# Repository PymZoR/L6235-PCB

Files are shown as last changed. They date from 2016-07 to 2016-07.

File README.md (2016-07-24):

# L6235-PCB

Implements the "typical application" ([datasheet](./doc/datasheet.pdf)) as a single sided PCB.  

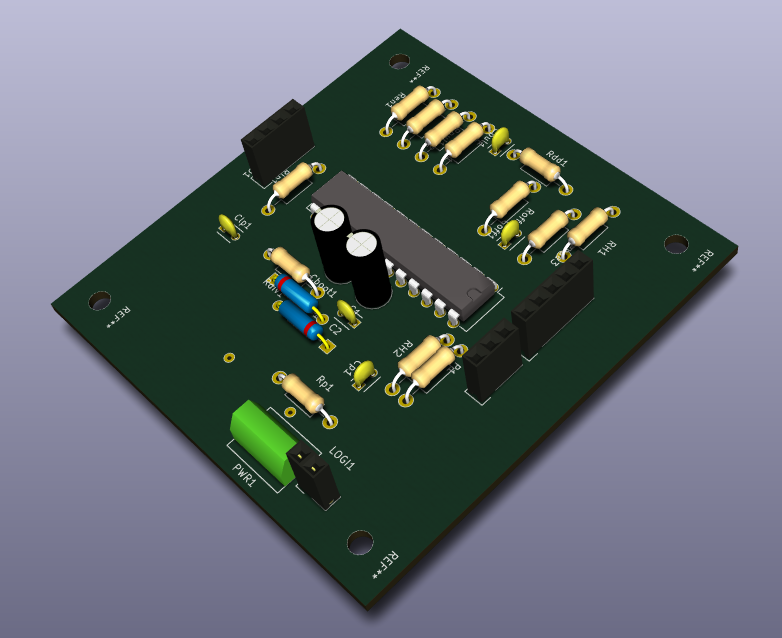
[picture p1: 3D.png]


## Specifications

- Require a 5V logic supply voltage (LOGI1), as well as a power one (PWR1)
- 69.8*66mm. 4 M3 mounting holes
- Variable reference voltage as described in the ([application note](./doc/application_note.pdf)) through VREF pin (CMD1)

## Schematic

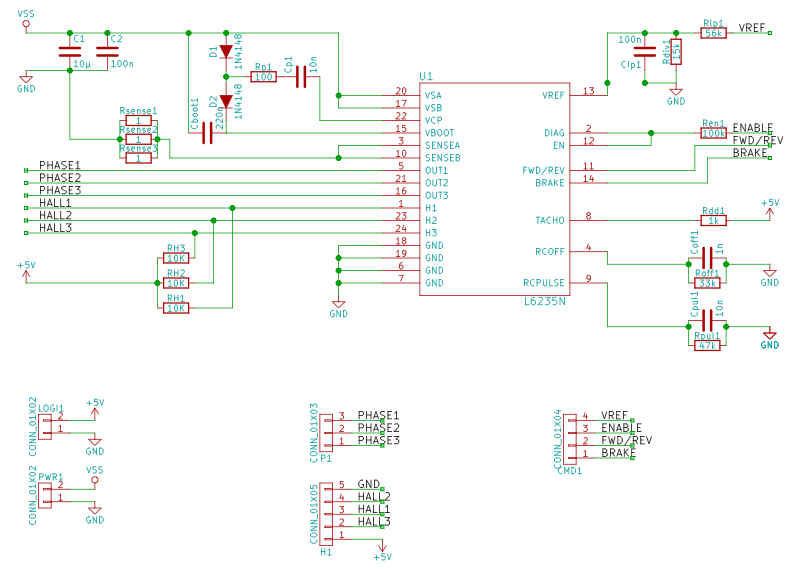
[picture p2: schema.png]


## PCB

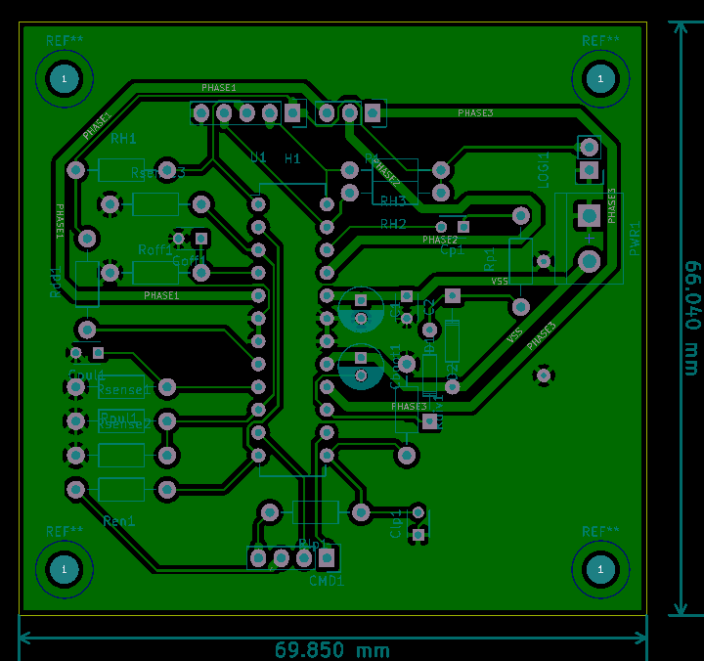
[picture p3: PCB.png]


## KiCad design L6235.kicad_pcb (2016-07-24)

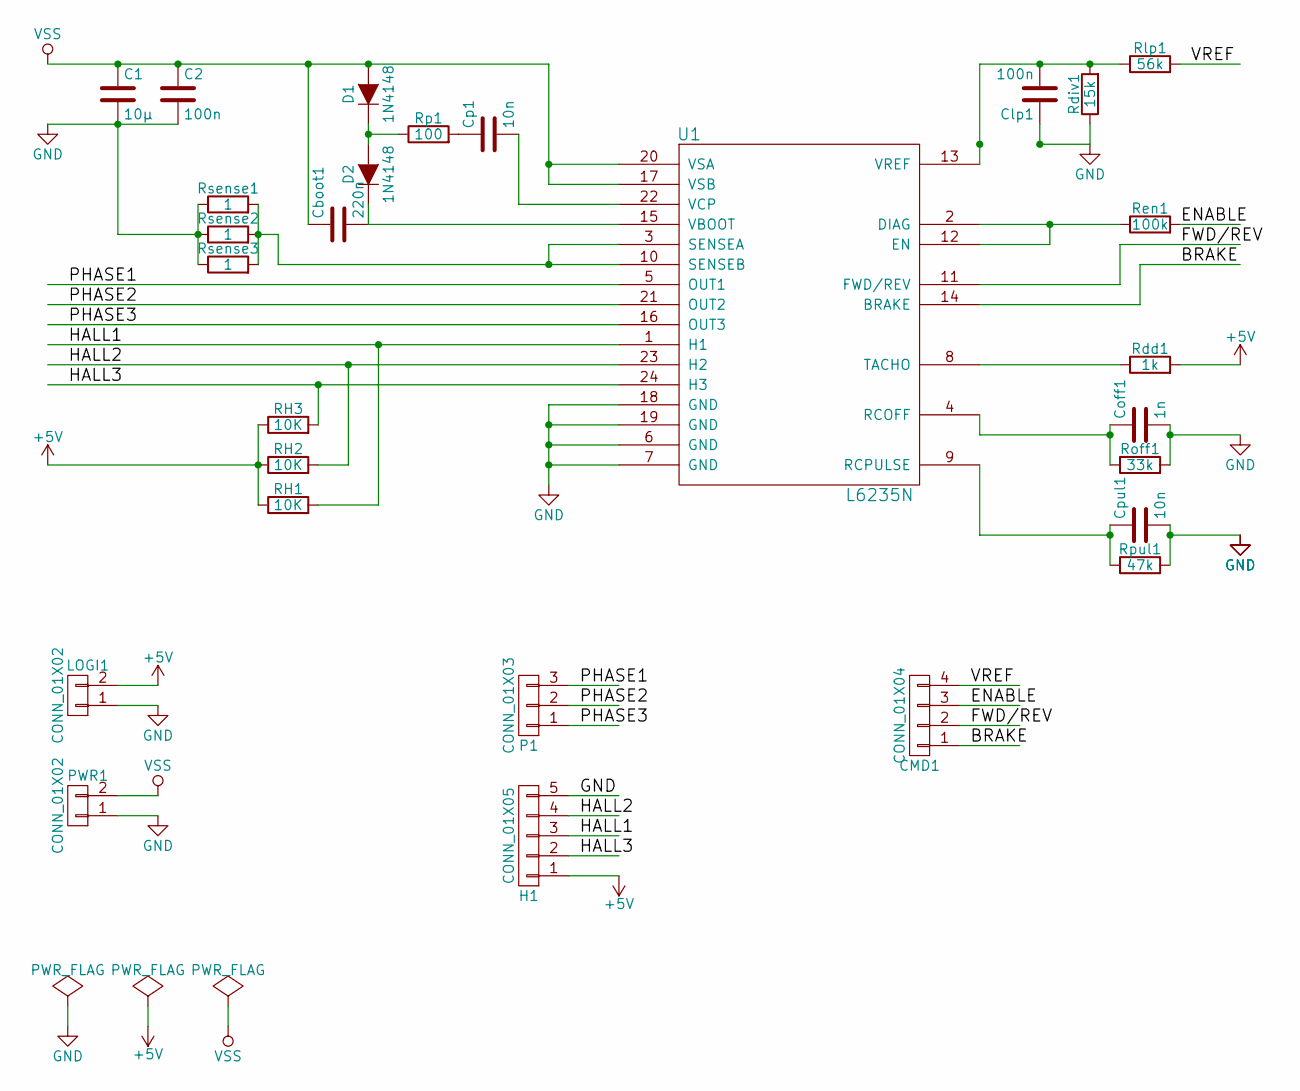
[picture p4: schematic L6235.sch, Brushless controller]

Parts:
C1: 10µ; C_Radial_D5_L11_P2
C2: 100n; C_Disc_D3_P2.5
CMD1: CONN_01X04; Socket_Strip_Straight_1x04
Cboot1: 220n; C_Radial_D5_L11_P2
Clp1: 100n; C_Disc_D3_P2.5
Coff1: 1n; C_Disc_D3_P2.5
Cp1: 10n; C_Disc_D3_P2.5
Cpul1: 10n; C_Disc_D3_P2.5
D1, D2: 1N4148; Diode_DO-35_SOD27_Horizontal_RM10
H1: CONN_01X05; Socket_Strip_Straight_1x05
LOGI1: CONN_01X02; Socket_Strip_Straight_1x02
P1: CONN_01X03; Socket_Strip_Straight_1x03
PWR1: CONN_01X02; bornier2
RH1, RH2, RH3: 10K; Resistor_Horizontal_RM10mm
Rdd1: 1k; Resistor_Horizontal_RM10mm
Rdiv1: 15k; Resistor_Horizontal_RM10mm
Ren1: 100k; Resistor_Horizontal_RM10mm
Rlp1: 56k; Resistor_Horizontal_RM10mm
Roff1: 33k; Resistor_Horizontal_RM10mm
Rp1: 100; Resistor_Horizontal_RM10mm
Rpul1: 47k; Resistor_Horizontal_RM10mm
Rsense1, Rsense2, Rsense3: 1; Resistor_Horizontal_RM10mm
U1: L6235N; DIP-24_W7.62mm

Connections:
+5V: H1.1, LOGI1.2, RH1.1, RH2.1, RH3.1, Rdd1.2
/BRAKE: CMD1.1, U1.14 (BRAKE)
/ENABLE: CMD1.3, Ren1.2
/FWD/REV: CMD1.2, U1.11 (FWD/REV)
/HALL1: H1.3, RH1.2, U1.1 (H1)
/HALL2: H1.4, RH2.2, U1.23 (H2)
/HALL3: H1.2, RH3.2, U1.24 (H3)
/PHASE1: P1.3, U1.5 (OUT1)
/PHASE2: P1.2, U1.21 (OUT2)
/PHASE3: P1.1, U1.16 (OUT3)
/VREF: CMD1.4, Rlp1.2
GND: C1.2, C2.2, Clp1.1, Coff1.2, Cpul1.2, H1.5, LOGI1.1, PWR1.1, Rdiv1.1, Roff1.2, Rpul1.2, Rsense1.1, Rsense2.1, Rsense3.1, U1.6 (GND), U1.7 (GND), U1.18 (GND), U1.19 (GND)
unnamed: Cboot1.2, D2.1 (K), U1.15 (VBOOT)
unnamed: Clp1.2, Rdiv1.2, Rlp1.1, U1.13 (VREF)
unnamed: Coff1.1, Roff1.1, U1.4 (RCOFF)
unnamed: Cp1.1, Rp1.2
unnamed: Cp1.2, U1.22 (VCP)
unnamed: Cpul1.1, Rpul1.1, U1.9 (RCPULSE)
unnamed: D1.1 (K), D2.2 (A), Rp1.1
unnamed: Rdd1.1, U1.8 (TACHO)
unnamed: Ren1.1, U1.2 (DIAG), U1.12 (EN)
unnamed: Rsense1.2, Rsense2.2, Rsense3.2, U1.3 (SENSEA), U1.10 (SENSEB)
VSS: C1.1, C2.1, Cboot1.1, D1.2 (A), PWR1.2, U1.17 (VSB), U1.20 (VSA)

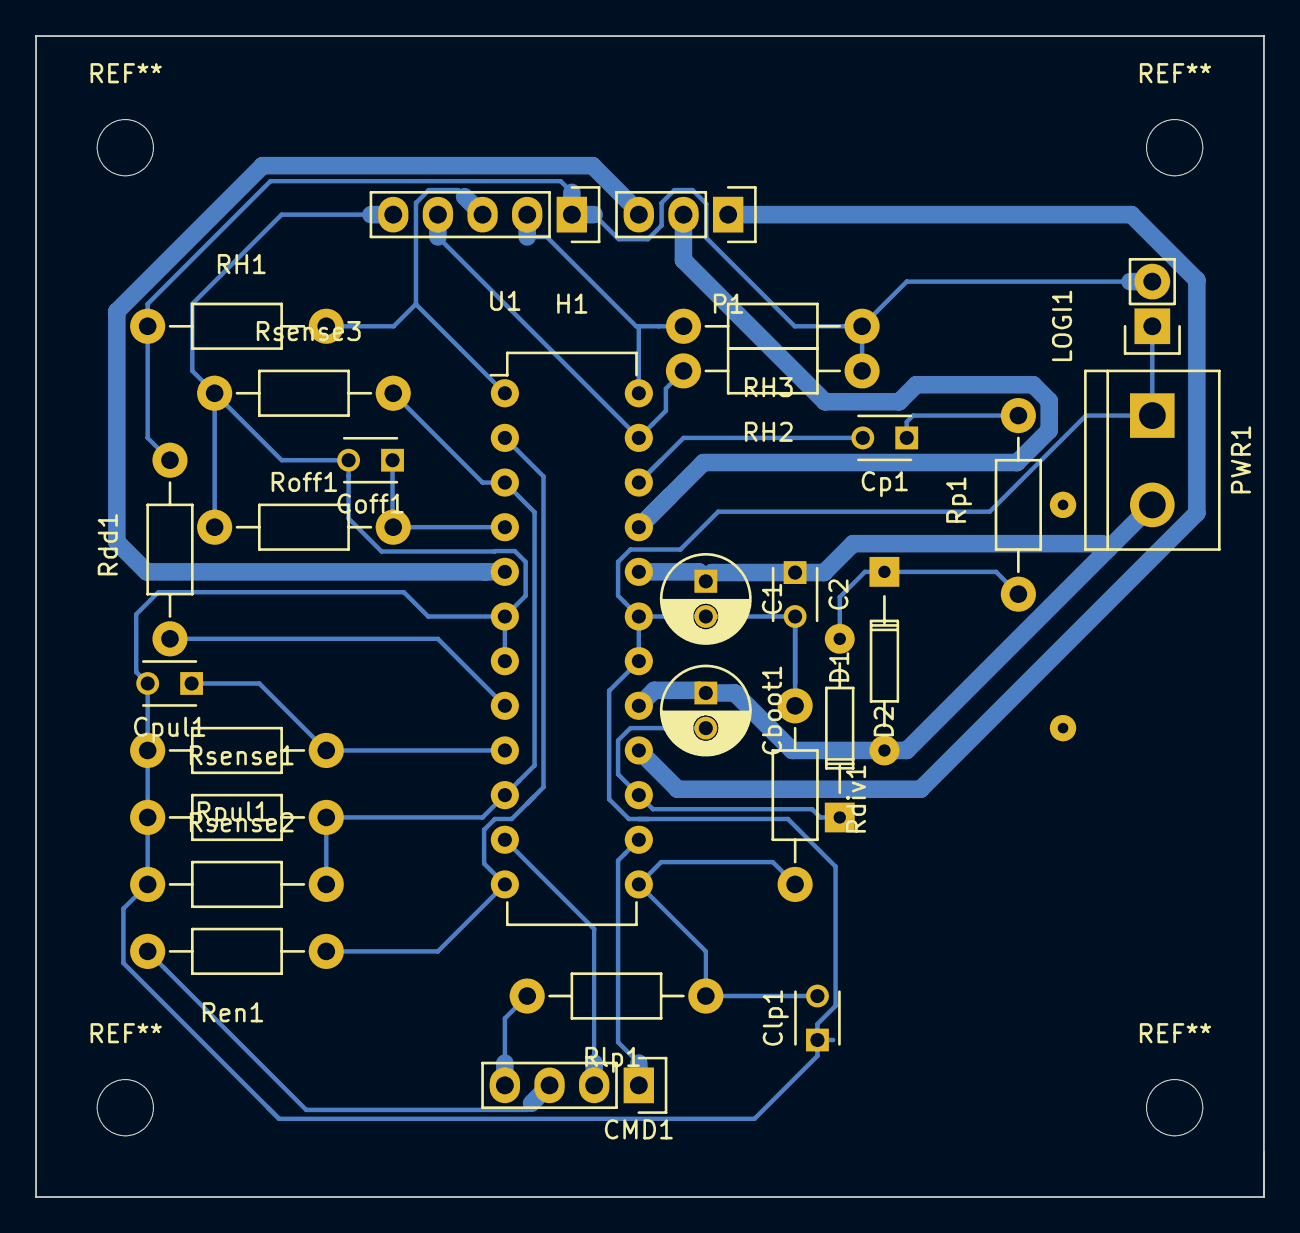
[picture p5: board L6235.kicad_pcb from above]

Board: 2 copper layers, 69.8 x 66.0 mm, 28 parts (0 on the bottom side), 23 nets.

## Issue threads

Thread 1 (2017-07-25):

Peak current

vitalibr, 2017-07-25:
The peak current of motor 42BLF02 is 10.2A, can I use its circuit for this motor?
**42BLF02**:
http://www.promoco-motors.com/products/BLDC/42BLF%20Series.pdf

Thanks for share with us!

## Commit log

2016-07-23 Add schema, PCB and lib
    [L6235.kicad_pcb, L6235.sch]
2016-07-24 fix: larger GND plan next to Phase2
    [L6235.kicad_pcb, L6235.sch]
2016-07-24 feature: add mounting holes; fix: add GND bridge
    [L6235.kicad_pcb]
